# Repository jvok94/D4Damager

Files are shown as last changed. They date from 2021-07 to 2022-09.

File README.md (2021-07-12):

# D4 Damager
The D4 Damager is a fully-featured broadcast audio processor for AM or FM broadcasting. It can also be used as a ham radio voice processor. The D4 Damager combines six main 
features:

* **Fast peak limiting:** Prevents loud sounds from overmodulating your transmitter.
* **Compression:** A high (variable) gain input stage allows you to optionally overdrive the limiter, turning it into a compressor. This increases your audio volume without 
overmodulating, allowing you to better overcome background noise and compete with other stations.
* **Peak clipping:** Catches brief transients that overshoot the limiter, to prevent even very brief overmodulation. The limiter ensures that any clipping will only be brief and 
so does not much affect the sound.
* **Pre-emphasis:** Required for all FM transmitters, a modified version of pre-emphasis can also be used with AM transmitters to improve clarity.
* **Variable de-emphasis:** Automatically rolls off some or all of the pre-emphasis as necessary to prevent overmodulation due to the high-frequency boost.
* **Low-pass filter**: Rolls off any high frequency content that exceeds the transmitter's allowed bandwidth.

Full technical documentation will be added as soon as I get round to it.

## D4 Damager Main Board

This board implements a complete mono audio processor. For mono operation, two input connectors (J5 and J6) are provided to sum stereo sources to mono. Two boards can be linked 
together for stereo operation by joining the "STEREO LINK" connector (J4) on each board.

The PCB includes a full power supply requiring only a 15-0-15VAC (30VAC center tapped) supply from an external transformer. The power supply on a single PCB is capable of 
powering a full stereo system including all accessories (simply leave the power supply components un-populated on the second PCB). +/-15VDC power is also available on the two 
"EXT PWR" connectors (J8 and J9). Alternatively these connectors can be used to power the D4 Damager from an external +/-15VDC regulated PSU, in which case there is no need to 
fit the power supply components on the main PCB.

Controls are provided for:

* **Input gain (RV6):** Used both to match the D4 Damager to the signal level from the external audio source, and also to control how hard the limiter is driven to achieve the 
desired amount of compression.
* **Release time (RV3):** Controls how quickly the compressor/limiter returns to full gain after a transient. Influences how aggressive the compressor will sound.
* **Ratio (RV1):** Sets the maximum gain of the compressor/limiter during quiet passages. Useful to prevent excessive gain from boosting background noise, hum, hiss, etc.
* **Clipper clearance (RV4):** Sets the difference (clearance) between the limiter's output level and the clipper's clipping level. Used to trade off between maximum volume and 
minimum distortion.
* **Output gain (RV5):** Used to match the output level to your transmitter. Has no affect on the sound.

In a mono system, you have the choice of using either PCB-mount potentiometers (Bourns PTD90 series), or external panel-mount potentiometers wired to the board. In a stereo 
system, you will need to use panel-mount dual gang potentiometers to control both channels at once. In this case the two series connected dual-gang 500k potentiometers (RV1 and 
RV3) can be replaced with single 1M units. Take care to use the correct potentiometer law (RV4-RV6 are antilog types, which are unusual).

## LED Meter Bridge

Optional accessory containing four separate six-segment LED meters showing:

* Input signal level/limiter drive (VU response ref. to +12VU)
* Limiter gain reduction (reads right-to-left as standard for compressors)
* Pre-emphasis reduction (reads right-to-left)
* Output signal level (VU response ref. to +6VU)

Single connection to the main PCB via "METER BRIDGE" connector (J3) carries all signals and power. Use two PCBs in a stereo system.

## Balanced IO Card

Converts unbalanced inputs and outputs from/to balanced signals for connection to professional studio equipment. Contains two balanced receivers for stereo input, and two 
balanced transmitters for stereo output. Additionally contains two MONITOR outputs which are fully de-emphasised to drive studio monitors. All balanced inputs and outputs are 
available on both XLR and 1/4" TRS connectors.

Powered from main PCB via "EXT PWR" connector (J8 or J9).

## BoM Versions

Several different BoM versions are available to account for different broadcast standards around the world:

* **BoM fm na.xlsx:** For FM broadcasters in ITU Region 2 (North/South America). 15kHz audio bandwidth, 75us pre-emphasis time constant.
* **BoM fm row.xlsx:** For FM broadcasters in ITU Regions 1 (Africa, Europe, Middle East, North Asia) and 3 (South Asia, Oceania). 15kHz audio bandwidth, 50us pre-emphasis time 
constant.
* **BoM am na.xlsx:** For AM broadcasters in ITU Region 2 (North/South America). 5kHz audio bandwdith, pre-emphasis according to NRSC-1-C curve.
* **BoM am row.xlsx:** For AM broadcasters in ITU Regions 1 (Africa, Europe, Middle East, North Asia) and 3 (South Asia, Oceania). 4.5kHz audio bandwidth, pre-emphasis 
according to modified version of NRSC-1-C curve for reduced bandwidth.

BoM variants apply to main PCB and balanced IO card. LED VU meter card is the same worldwide.

## Initial calibration

You will need:

* Multimeter or DC voltmeter
* Dual-channel oscilloscope or audio millivolt meter
* Sine wave audio signal generator (you can use an app on your phone/PC for this, e.g. https://play.google.com/store/apps/details?id=com.keuwl.functiongenerator)

### Main PCB

Calibration should be done with no signal applied.

1. Adjust RV2 (SET DC) for 0.0mV DC offset on U1 pin 7.
2. Adjust RV7 (SET DC) for 0.0mV DC offset on U6 pin 1.

### LED VU Meter

Calibration should be done with LED VU meter PCB connected to main PCB. Make sure controls on main PCB are set as follows:

* RV1, RV3 fully clockwise.
* RV4, RV5, RV6 fully counter-clockwise.

1. Adjust RV1 (on the LED VU meter PCB) for -1.736VDC at junction of R6/R7.
2. Connect signal generator to main PCB input connector (J5). Do not apply a signal yet.
3. Connect oscilloscope channel 1 probe to main PCB input connector (J6), and channel 2 probe to main PCB output connector (J1). Use the connector shells for the ground clips.
4. Set signal generator output to 100mV p-p at 1kHz.
5. By comparing the signal levels on oscilloscope channels 1/2, measure the system gain.
6. Increase the signal generator output voltage while monitoring the gain on the oscilloscope, until the system gain has fallen 18dB below the previously measured level. This 
will require some back-and-forth between the signal generator and the oscilloscope.
7. Adjust RV3 (on the LED VU meter PCB) until D17 just lights up.
8. Without changing any signal levels, measure the DC voltage at U3 pin 6 on the main PCB.
9. Adjust the signal generator output level until the DC voltage at U3 pin 2 on the main PCB matches the voltage measured in step 8.
10. Adjust RV2 (on the LED VU meter PCB) until D23 just lights up.

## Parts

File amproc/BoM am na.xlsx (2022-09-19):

Reference | Quantity | Value | Footprint | Description | Manufacturer | Part number | Supplier | Order code | Price | Total | Notes
C1 C25 | 2 | 100p | Radial disc W4mm T2.6mm S2.5mm | 100pF 50V 5% C0G | Vishay | K101J15C0GF5TL2 | Farnell | 2860078 | £0.0713 | £0.1426
C10 C27 | 2 | 470p | Radial disc W4mm T2.5mm S5mm | 470pF 60V 5% C0G | Murata | RDE5C1H471J0M1H03A | Farnell | 2990775 | £0.1600 | £0.3200
C14 C13 | 2 | 1000u 35V | Radial can D12mm S5mm | 1000uF 35V 20% 105C electrolytic | Kemet | ESY108M035AL4AA | Farnell | 2835188 | £0.4390 | £0.8780
C17 C18 C19 C21 C20 C22 C23 | 7 | 100n | Radial disc W4mm T2.6mm S5mm | 100nF 50V 10% X7R | Vishay | K104K15X7RF53H5 | Farnell | 1141777 | £0.0823 | £0.5761
C3 C7 | 2 | 100n | Radial box W7.2mm T2.5mm S5mm | 100nF 63V 10% film | Kemet | R82DC3100AA50K | Farnell | 2763208 | £0.1280 | £0.2560
C24 | 1 | 150n | Radial box W7.2mm T2.5mm S5mm | 150nF 63V 10% film | Kemet | R82DC3150DQ60K | Farnell | 2446334 | £0.1370 | £0.1370
C26 C29 C16 C15 C9 C30 | 6 | 47u 25V | Radial can D5mm S2mm | 47uF 25V 20% 105C electrolytic | Kemet | ESH476M025AC3AA | Farnell | 2068762 | £0.0745 | £0.4470
C4 C11 C28 | 3 | 1n | Radial box W7.2mm T2.5mm S5mm | 1nF 100V 5% film | Kemet | R82EC1100Z350J | Farnell | 1679411 | £0.1300 | £0.3900
C5 | 1 | 4n7 | Radial box W7.2mm T2.5mm S5mm | 4.7nF 100V 10% film | Kemet | R82EC1470DQ50K | Farnell | 2763226 | £0.1100 | £0.1100
C8 C12 C6 C2 | 4 | 1u | Radial box W7.2mm T5mm 5mm | 1uF 63V 10% film | Kemet | R82DC4100AA60K | Farnell | 2763215 | £0.2750 | £1.1000
D13 | 1 | RED | T1-3/4 | 5mm 10mA red LED | Multicomp | MCL053PD | Farnell | 1581136 | £0.0609 | £0.0609
D4 D5 D6 D1 D2 D3 | 6 | 1N4148 | DO-35/DO-204AH | 100V 150mA silicon signal diode | Multicomp | 1N4148 (DO-35) | Farnell | 2675146 | £0.0319 | £0.1914
D7 D8 D9 D10 D12 D11 | 6 | 1N4001 | DO-204AL | 50V 1A silicon power diode | ON Semiconductor | 1N4001RLG | Farnell | 2822512 | £0.1930 | £1.1580
J1 J5 J6 | 3 |  | NYS354 | NYS354 | Rean | NYS354 | Mouser | 568-NYS354 | £0.5900 | £1.7700
J2 | 1 | AC IN | 39-28-1043 | 2x2-pin 4.20mm pitch shrouded header | Molex | 39-28-1043 | Farnell | 9732098 | £0.5810 | £0.5810 | Mates with Molex 39-01-2040 housing
J3 | 1 | METER BRIDGE | B7B-XH-A | 1x7-pin 2.5mm pitch shrouded header | JST | B7B-XH-A (LF)(SN) | Farnell | 1516283 | £0.2470 | £0.2470 | Mates with JST XHP-7
J4 | 1 | STEREO LINK | B5B-XH-A | 1x5-pin 2.5mm pitch shrouded header | JST | B5B-XH-A (LF)(SN) | Farnell | 1516281 | £0.1320 | £0.1320 | Mates with JST XHP-5
J7 | 1 | CHASSIS | TAB37800568 | 2.8x0.51mm PCB terminal | JST | TAB 37800568(MSTIN) | Farnell | 3625552 | £0.0252 | £0.0252 | Mates with any 2.8x0.51mm crimp terminal
J8 J9 | 2 | EXT POWER | B3B-XH-A | 1x3-pin 2.5mm pitch shrouded header | JST | B3B-XH-A (LF)(SN) | Farnell | 1516277 | £0.0925 | £0.1850
Q5 Q3 Q2 | 3 | BC546 | TO-92 | 100mA 65V NPN BJT | ON Semiconductor | BC546BTF | Farnell | 2453787 | £0.1510 | £0.4530
Q8 Q7 Q9 Q6 Q4 Q1 | 6 | BC556 | TO-92 | 100mA 65V PNP BJT | ON Semiconductor | BC556BTF | Farnell | 2453802 | £0.1640 | £0.9840
R10 | 1 | 430k | Axial 6.8mm | 530k 0.6W 1% metal film | Multicomp | MCMF006FF4303A50 | Farnell | 2401823 | £0.0207 | £0.0207
R13 R4 | 2 | 56 | Axial 6.8mm | 56R 0.6W 1% metal film | Multicomp | MCMF006FF560JA50 | Farnell | 2401720 | £0.0288 | £0.0576
R14 | 1 | 75k | Axial 6.8mm | 75k 0.6W 1% metal film | Multicomp | MCMF006FF7502A50 | Farnell | 2401804 | £0.0288 | £0.0288
R19 R3 | 2 | 8k2 | Axial 6.8mm | 8.2k 0.6W 1% metal film | Multicomp | MCMF006FF8201A50 | Farnell | 2401778 | £0.0284 | £0.0568
R2 | 1 | 82k | Axial 6.8mm | 82k 0.6W 1% metal film | Multicomp | MCMF006FF8202A50 | Farnell | 2401805 | £0.0300 | £0.0300
R20 | 1 | 3k9 | Axial 6.8mm | 3.9k 0.6W 1% metal film | Multicomp | MCMF006FF3901A50 | Farnell | 2401768 | £0.0302 | £0.0302
R21 | 1 | 12k | Axial 6.8mm | 12k 0.6W 1% metal film | Multicomp | MCMF006FF1202A50 | Farnell | 2401783 | £0.0284 | £0.0284
R24 | 1 | 270k | Axial 6.8mm | 270k 0.6W 1% metal film | Multicomp | MCMF006FF2703A50 | Farnell | 2401818 | £0.0286 | £0.0286
R26 | 1 | 22k | Axial 6.8mm | 22k 0.6W 1% metal film | Multicomp | MCMF006FF2202A50 | Farnell | 2401789 | £0.0300 | £0.0300
R30 | 1 | 3k3 | Axial 6.8mm | 3.3k 0.6W 1% metal film | Multicomp | MCMF006FF3301A50 | Farnell | 2401766 | £0.0288 | £0.0288
R31 R45 | 2 | 24k | Axial 6.8mm | 24k 0.6W 1% metal film | Multicomp | MCMF006FF2402A50 | Farnell | 2401790 | £0.0379 | £0.0758
R32 R46 | 2 | 15k | Axial 6.8mm | 15k 0.6W 1% metal film | Multicomp | MCMF006FF1502A50 | Farnell | 2401785 | £0.0379 | £0.0758
R34 R15 R18 R7 R5 | 5 | 100 | Axial 6.8mm | 100R 0.6W 1% metal film | Multicomp | MCMF006FF1000A50 | Farnell | 2401727 | £0.0300 | £0.1500
R36 | 1 | 68k | Axial 6.8mm | 68k 0.6W 1% metal film | Multicomp | MCMF006FF6802A50 | Farnell | 2401803 | £0.0288 | £0.0288
R37 R38 | 2 | 470 | Axial 6.8mm | 470R 0.6W 1% metal film | TE Connectivity | LR1F470R | Farnell | 2330156 | £0.0786 | £0.1572
R39 R40 R41 R27 | 4 | 27k | Axial 6.8mm | 27k 0.6W 1% metal film | Multicomp | MCMF006FF2702A50 | Farnell | 2401791 | £0.0284 | £0.1136
R42 R35 R16 R12 R6 | 5 | 2k2 | Axial 6.8mm | 2.2k 0.6W 1% metal film | Multicomp | MCMF006FF2201A50 | Farnell | 2401762 | £0.0283 | £0.1415
R43 R29 R1 | 3 | 100k | Axial 6.8mm | 100k 0.6W 1% metal film | Multicomp | MCMF006FF1003A50 | Farnell | 2401807 | £0.0284 | £0.0852
R44 | 1 | 560 | Axial 6.8mm | 560R 0.6W 1% metal film | Multicomp | MCMF006FF5600A50 | Farnell | 2401747 | £0.0288 | £0.0288
R47 R28 R33 R23 R17 R25 R22 R9 R11 R8 | 11 | 10k | Axial 6.8mm | 10k 0.6W 1% metal film | Multicomp | MCMF006FF1002A50 | Farnell | 2401780 | £0.0288 | £0.3168
R48 | 1 | 10 | Axial 6.8mm | 10R 0.6W 1% metal film | Multicomp | MCMF006FF100JA50 | Farnell | 2401700 | £0.0288 | £0.0288
RV1 RV3 | 2 | 500k LIN | PTD902 | 500k dual gang linear potentiometer | Bourns | PTD902-1015K-B504 | Mouser | 652-PTD9021015KB504 | £1.5000 | £3.0000
RV2 RV7 | 2 | 100 | T93YA | 100R multiturn trimmer | Vishay | T93YA101KT20 | Farnell | 1141397 | £1.4000 | £2.8000
RV6 RV5 RV4 | 3 | 10k ANTILOG | PTD901 | 10k single gang antilog potentiometer | Bourns | PTD901-2015F-C103 | Mouser | 652-PTD9012015FC103 | £1.2500 | £3.7500
U1 U2 U3 U5 U6 U7 | 6 | TL072 | DIP-8 | Dual 36V JFET input opamp | Texas Instruments | TL072ACP | Farnell | 3117783 | £0.9050 | £5.4300
U4 | 1 | LM13700 | DIP-16 | Dual OTA | Texas Instruments | LM13700N/NOPB | Farnell | 3118206 | £1.8400 | £1.8400
U8 | 1 | L7815 | TO-220 | Positive 15V linear regulator | ON Semiconductor | MC7815ACTG | Farnell | 2382331 | £0.4600 | £0.4600
U9 | 1 | L7915 | TO-220 | Negative 15V linear regulator | ON Semiconductor | MC7915ACTG | Mouser | 863-MC7915ACTG | £0.4040 | £0.4040
 |  |  |  |  |  |  |  |  | Total | £29.37

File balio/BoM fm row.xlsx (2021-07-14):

Reference | Quantity | Value | Footprint | Description | Manufacturer | Part number | Supplier | Order code | Price | Total | Notes
C1 C8 C9 C2 C11 C12 | 6 | 560p | Radial disc W4mm T2.6mm S2.5mm | 560pF 50V 5% C0G | Vishay | K561J15C0GF5TL2 | Farnell | 2860139 | £0.1350 | £0.8100
C3 C4 C5 C6 | 4 | 100n | Radial disc W4mm T2.6mm S5mm | 100nF 50V 10% X7R | Vishay | K104K15X7RF53H5 | Farnell | 1141777 | £0.0823 | £0.3292
C7 C10 | 2 | 1n5 | Radial box W7.2mm T2.5mm S5mm | 1.5nF 100V 5% film | Kemet | R82EC1150Z350J | Farnell | 1679412 | £0.1350 | £0.2700
C13 C14 | 2 | 100u 25V | Radial can D6mm S2.5mm | 100uF 25V 20% 85C electrolytic | Kemet | ESK107M025AE3AA | Farnell | 2068981 | £0.0805 | £0.1610
J1 J2 | 2 |  | NC3FAAH2 | 3-pin XLR female PCB mount | Neutrik | NC3FAAH2 | Farnell | 1310023 | £0.9390 | £1.8780
J3 J4 J11 J12 J15 J16 | 6 |  | CL12345 | 6.35mm TRS PCB mount | Cliff | CL12345 | Farnell | 2766186 | £1.1800 | £7.0800
J5 J6 J7 J8 | 4 |  | NYS354 | NYS354 | Rean | NYS354 | Mouser | 568-NYS354 | £0.5900 | £2.3600
J9 J10 J13 J14 | 4 |  | NC3MAAH | 3-pin XLR male PCB mount | Neutrik | NC3MAAH | Farnell | 1310044 | £0.8790 | £3.5160
J17 J18 | 2 | POWER | B3B-XH-A | 1x3-pin 2.5mm pitch shrouded header | JST | B3B-XH-A (LF)(SN) | Farnell | 1516277 | £0.0925 | £0.1850
R1 R2 R3 R4 R24 R26 R23 R25 R27 R29 R28 R30 | 12 | 2k2 | Axial 6.8mm | 2.2k 0.6W 1% metal film | Multicomp | MCMF006FF2201A50 | Farnell | 2401762 | £0.0283 | £0.3396
R5 R9 R13 R10 R11 R14 R12 R6 R17 R21 R18 R19 R22 R20 | 14 | 220 | Axial 6.8mm | 220R 0.6W 1% metal film | Multicomp | MCMF006FF2200A50 | Farnell | 2401736 | £0.0288 | £0.4032
R7 R15 | 2 | 30k | Axial 6.8mm | 30k 0.6W 1% metal film | Multicomp | MCMF006FF3002A50 | Farnell | 2401792 | £0.0307 | £0.0614
R8 R16 | 2 | 3k6 | Axial 6.8mm | 3.6k 0.6W 1% metal film | Multicomp | MCMF006FF3601A50 | Farnell | 2401767 | £0.0282 | £0.0564
U1 U2 | 2 | INA134 | DIP-8 | 36V balanced audio receiver | Texas Instruments | INA134PA | Farnell | 3005742 | £2.9000 | £5.8000
U3 U4 | 2 | TL072 | DIP-8 | Dual 36V JFET input opamp | Texas Instruments | TL072ACP | Farnell | 3117783 | £0.9050 | £1.8100
 |  |  |  |  |  |  |  |  | Total | £25.06

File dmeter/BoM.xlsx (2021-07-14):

Reference | Quantity | Value | Footprint | Description | Manufacturer | Part number | Supplier | Order code | Price | Total | Notes
C1 C2 | 2 | 100u 25V | Radial can D6mm S2.5mm | 100uF 25V 20% 85C electrolytic | Kemet | ESK107M025AE3AA | Farnell | 2068981 | £0.0805 | £0.1610
C11 C12 | 2 | 560n | Radial box W7.2mm T4.5mm S5mm | 560nF 63V 10% film | Kemet | MMK5564K63J03L4BULK | Mouser | 80-MMK5564K63J03L4 | £0.4650 | £0.9300
C3 C4 C5 C6 C9 C10 C13 C14 C15 C16 | 10 | 100n | Radial disc W4mm T2.6mm S5mm | 100nF 50V 10% X7R | Vishay | K104K15X7RF53H5 | Farnell | 1141777 | £0.0823 | £0.8230
C7 C8 | 2 | 33p | Radial disc W4mm T2.5mm S2.5mm | 33pF 50V 5% C0G | Vishay | K330J15C0GF5TL2 | Farnell | 2860122 | £0.0970 | £0.1940
D1 D5 D3 D2 D6 D4 D7 D8 | 8 | 1N4148 | DO-35/DO-204AH | 100V 150mA silicon signal diode | Multicomp | 1N4148 (DO-35) | Farnell | 2675146 | £0.0319 | £0.2552
D13 D31 | 2 | YELLOW | T1-3/4 | 5mm 20mA yellow LED | Multicomp | MCL053YD | Farnell | 1581139 | £0.0958 | £0.1916
D14 D32 | 2 | RED | T1-3/4 | 5mm 10mA red LED | Multicomp | MCL053PD | Farnell | 1581136 | £0.0609 | £0.1218
D9 D10 D11 D12 D15 D16 D17 D18 D19 D20 D21 D22 D23 D24 D25 D26 D27 D28 D29 D30 | 20 | GREEN | T1-3/4 | 5mm 20mA green LED | Multicomp | MCL053GD | Farnell | 1581138 | £0.0746 | £1.4920
J1 | 1 | INPUT | B7B-XH-A | 1x7-pin 2.5mm pitch shrouded header | JST | B7B-XH-A (LF)(SN) | Farnell | 1516283 | £0.2470 | £0.2470 | Mates with JST XHP-7
Q2 Q3 Q4 Q5 Q1 | 5 | BC556 | TO-92 | 100mA 65V PNP BJT | ON Semiconductor | BC556BTF | Farnell | 2453802 | £0.1640 | £0.8200
R1 R2 | 2 | 1k | Axial 6.8mm | 1k 0.6W 1% metal film | Multicomp | MCMF006FF1001A50 | Farnell | 2401753 | £0.0303 | £0.0606
R11 R21 | 2 | 390 | Axial 6.8mm | 390R 0.6W 1% metal film | Multicomp | MCMF006FF3900A50 | Farnell | 2401742 | £0.0288 | £0.0576
R13 R10 R15 R8 R17 R14 R12 R16 R9 R19 R24 R25 R27 | 13 | 10k | Axial 6.8mm | 10k 0.6W 1% metal film | Multicomp | MCMF006FF1002A50 | Farnell | 2401780 | £0.0288 | £0.3744
R20 R18 | 2 | 1M | Axial 6.8mm | 1M 0.6W 1% metal film | Multicomp | MCMF006FF1004A50 | Farnell | 2401833 | £0.0300 | £0.0600
R26 | 1 | 30k | Axial 6.8mm | 30k 0.6W 1% metal film | Multicomp | MCMF006FF3002A50 | Farnell | 2401792 | £0.0307 | £0.0307
R28 R22 R23 | 3 | 5k6 | Axial 6.8mm | 5.6k 0.6W 1% metal film | Multicomp | MCMF006FF5601A50 | Farnell | 2401774 | £0.0281 | £0.0843
R29 R30 R31 R32 | 4 | 100 | Axial 6.8mm | 100R 0.6W 1% metal film | Multicomp | MCMF006FF1000A50 | Farnell | 2401727 | £0.0300 | £0.1200
R3 | 1 | 2k | Axial 6.8mm | 2k 0.6W 1% metal film | Multicomp | MCMF006FF2001A50 | Farnell | 2401761 | £0.0300 | £0.0300
R4 | 1 | 3k9 | Axial 6.8mm | 3.9k 0.6W 1% metal film | Multicomp | MCMF006FF3901A50 | Farnell | 2401768 | £0.0302 | £0.0302
R5 | 1 | 8k2 | Axial 6.8mm | 8.2k 0.6W 1% metal film | Multicomp | MCMF006FF8201A50 | Farnell | 2401778 | £0.0284 | £0.0284
R6 | 1 | 16k | Axial 6.8mm | 16k 0.6W 1% metal film | Multicomp | MCMF006FF1602A50 | Farnell | 2401786 | £0.0286 | £0.0286
R7 | 1 | 240k | Axial 6.8mm | 240k 0.6W 1% metal film | Multicomp | MCMF006FF2403A50 | Farnell | 2401817 | £0.0266 | £0.0266
RV1 RV2 RV3 | 3 | 10k | T93YA | 10k multiturn trimmer | Vishay | T93YA103KT20 | Farnell | 1141404 | £1.4400 | £4.3200
U1 U2 U3 U4 | 4 | TL072 | DIP-8 | Dual 36V JFET input opamp | Texas Instruments | TL072ACP | Farnell | 3117783 | £0.9050 | £3.6200
U5 U6 U7 U8 U9 U10 | 6 | LM339 | DIP-14 | Quad 36V open-drain output comparator | Texas Instruments | LM339AN | Farnell | 3118450 | £0.4770 | £2.8620
 |  |  |  |  |  |  |  |  | Total | £16.97

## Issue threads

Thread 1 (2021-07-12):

J2 on main PCB - pin dimensions wrong

jvok94, 2021-07-12:
"AC IN" connector (J2) on main PCB, hole dimensions are too small to fit the pins. Had to wire transformer directly to PCB as workaround.

Increase these hole dimensions to match recommended footprint in datasheet: https://www.molex.com/pdm_docs/sd/039281043_sd.pdf

jvok94, 2021-07-17:
Fixed in commit 2672a2ff3da69e6f78261edbda0c9bd560d376c6

Closed 2021-07-17.

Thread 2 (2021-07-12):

Excessive high-frequency roll-off due to C25

jvok94, 2021-07-12:
Capacitor C25 on main PCB forms part of a passive LPF at the input to prevent RF interference from getting into the card. However the current value (560pF) causes a bit too much attenuation at high-frequencies when combined with the main audio LPFs. Changing this to 100pF will still give enough RF attenuation without attenuating audio frequencies.

jvok94, 2021-07-14:
Implemented in commit c5f9b9964f1abe7292039a8ce1eda6c55f51f18e

Closed 2021-07-12.

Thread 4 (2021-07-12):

Correct reference levels of input and output meters

jvok94, 2021-07-12:
On LED VU Meter board, labelling on schematic suggests full scale for input meter is +12VU, and for output meter is +6VU. However looking at values of attenuators (R26/R27 for input meter, R24/R25 for output meter), this is actually the other way round, i.e. +6VU full scale on input meter, +12VU full scale on output meter.

Need to change attenuator resistors so that meter response matches labelling.

jvok94, 2021-07-14:
Implemented in commit 27dbdb92ca757b2c75ce1d5698e8d7ae3e768ec6

Closed 2021-07-12.

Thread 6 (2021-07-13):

Review pre-emphasis circuit component values

jvok94, 2021-07-13:
While working on #5 it was discovered that the wrong formula had been used in the spreadsheet to calculate the zero frequency. The formula uses the calculated ideal resistor value for R20 instead of the actual (closest E24) value. These results are used to compare multiple different component selections and choose the one with the lowest error. As a result, the values chosen might not actually be the best possible choices.

Review all design variants to make sure the components used actually give the closest match to the proper pre-emphasis curve, and update schematic and BoM if necessary. Don't need to do this for AM RoW variant as this has already been done as part of #5.

jvok94, 2021-07-17:
Fixed in commit 3e532c62e887ab937022e106463bf8e8b192fe5a

Closed 2021-07-17.

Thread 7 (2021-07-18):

Limiter/de-emphasis metering feeds after envelope filter

jvok94, 2021-07-18:
Currently the limiter gain reduction meter and de-emphasis meter are both driven directly from the rectifier outputs (pulsed DC) rather than from the envelope filter (slowly changing DC). This makes the meters very flickery and fast responding, particularly noticeable against the much slower responding input/output VU meters.

It also means that the meters do not accurately show how the limiter and de-emphasis are responding. During the attack period especially the meter will tend to read higher than it should due to the voltage drop across the attack timing resistor.

Circuit should be changed to take metering feeds directly from the envelope filter capacitor (C3/C7). Note that the stereo link connector should still go to the rectifier output.

N.b. might want to prototype this first.

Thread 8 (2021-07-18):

Changes to allow lower value pots for release and ratio controls

jvok94, 2021-07-18:
Both the release time (RV3) and ratio (RV1) controls need 1M pots. As these are not widely available, dual-gang 500k pots have been used instead, with the two gangs connected in series. This is fine for a mono setup, but for a stereo setup we'd need either a dual-gang 1M pot or a quad-gang 500k pot, neither of which is easy to find.

Try to come up with a circuit change that will allow the use of lower value pots without changing functionality. See also issue #9.

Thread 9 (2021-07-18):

Eliminate anti-log pots

jvok94, 2021-07-18:
Anti-log pots have been used for the input gain (RV2), output gain (RV5) and clipper headroom (RV4) controls. This is needed to get the correct logarithmic response as the pots are used in the feedback loops of opamps. However anti-log pots are more expensive and harder to find, especially in dual-gang versions (for a stereo unit).

See if circuit design can be changed to take pots outside of feedback loops, allowing normal log pots to be used.

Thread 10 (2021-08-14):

Voltage regulator pin-outs backwards

jvok94, 2021-08-14:
U8/U9 are intended to mount on bottom of PCB, but with tabs facing downwards for attaching to heatsink. On Rev. 1 design, standard horizontal TO-220 footprints were used but flipped to bottom layer. This incorrectly reverses pinout so regulator had to be mounted with tab facing upwards (in contact with PCB).

Can correct pinout by either putting footprints on top layer (despite mount on bottom layer), or better by using footprint designed for reverse mounting.

jvok94, 2022-09-19:
Fixed in commit 62207d1cf0d763c8c085fba6087937c6c2914390

Closed 2022-09-19.

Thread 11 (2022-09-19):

Migrate to Kicad 6

jvok94, 2022-09-19:

jvok94, 2022-09-19:
Fixed in commits b8368e85c7e27e8f117ae28eea41ff454eb6720c, 632c7e6a15b64aa0ff80a88db13cf60ca302454e and f54c9045ebc5bec713ae23f7bd7639c6c33cc0b2

Closed 2022-09-19.

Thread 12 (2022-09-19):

Rev 2 release

jvok94, 2022-09-19:
- Full check of schematic and PCB layout
- Check all BoMs match up with schematic
- Re-plot gerbers
- Full check of gerbers

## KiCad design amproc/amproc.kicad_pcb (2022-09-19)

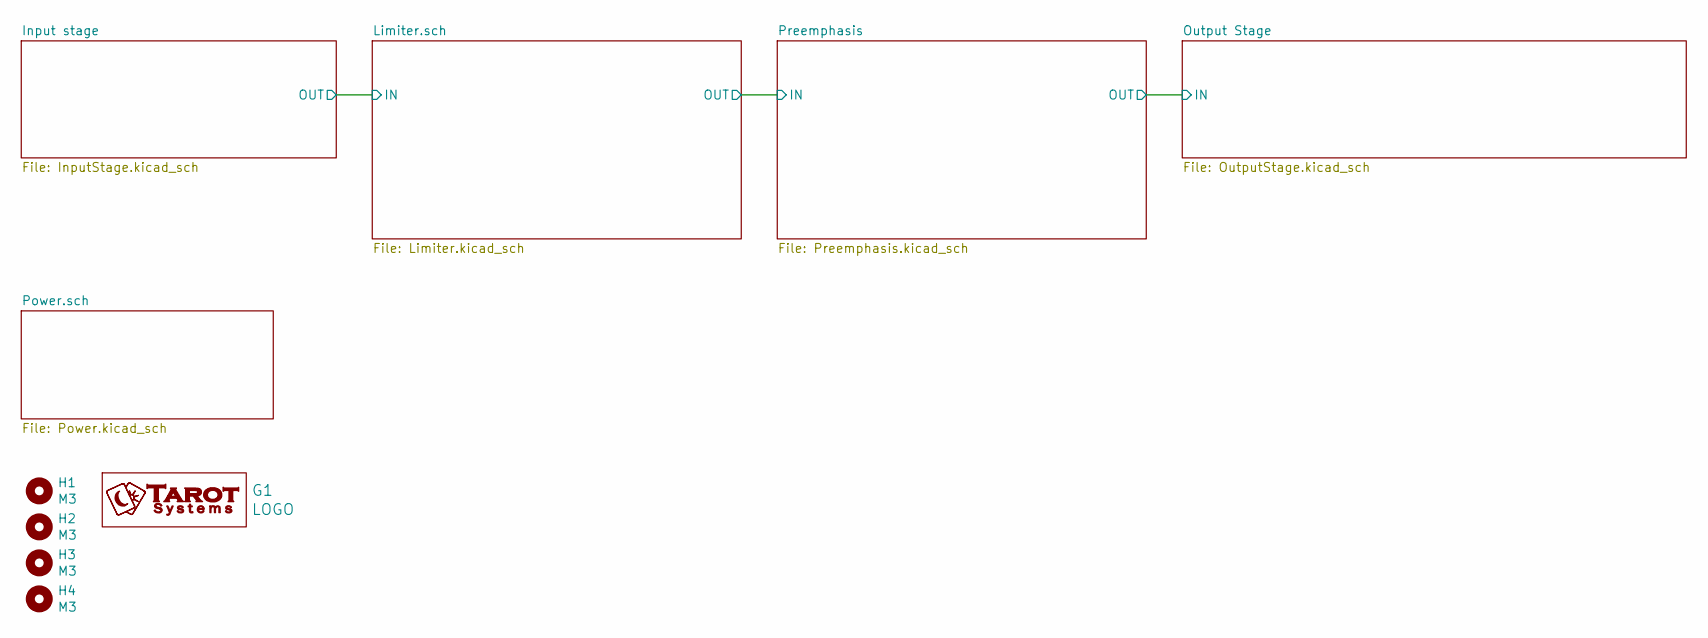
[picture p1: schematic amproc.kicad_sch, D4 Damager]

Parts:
G1: LOGO; tarot_logo_fsilk_25mm
H1, H2, H3, H4: M3; MountingHole_3.2mm_M3

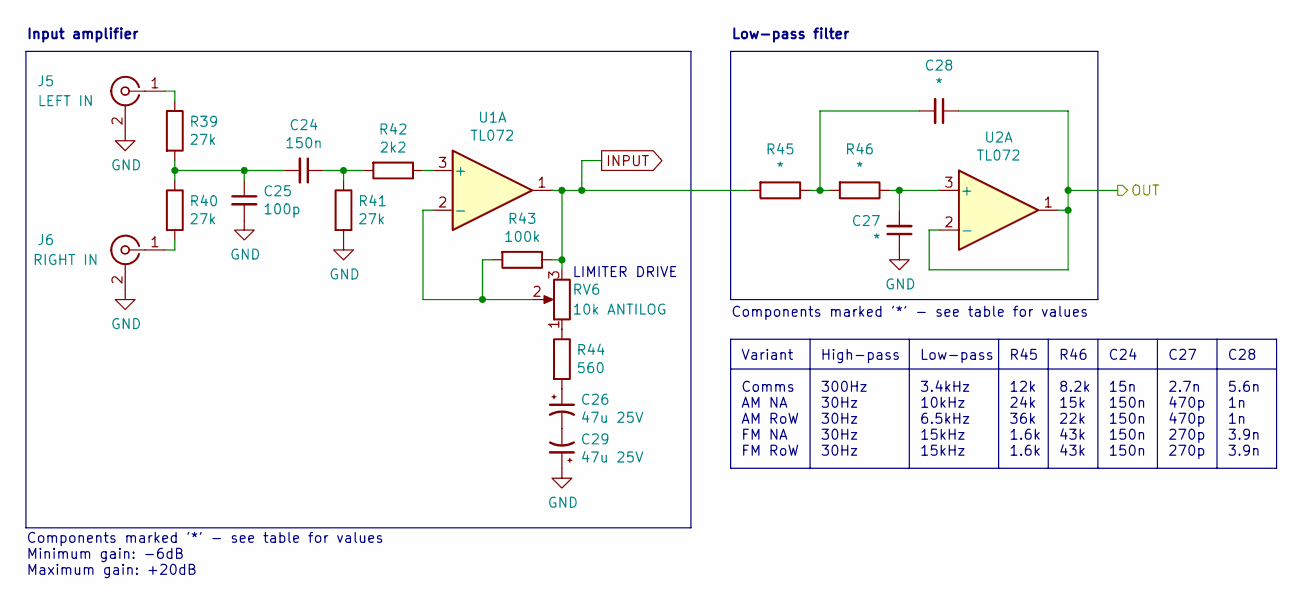
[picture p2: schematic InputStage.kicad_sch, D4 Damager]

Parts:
C24: 150n; C_Rect_L7.2mm_W2.5mm_P5.00mm_FKS2_FKP2_MKS2_MKP2
C25: 100p; C_Disc_D5.0mm_W2.5mm_P2.50mm
C26, C29: 47u 25V; CP_Radial_D5.0mm_P2.00mm
C27, C28: *; C_Rect_L7.2mm_W2.5mm_P5.00mm_FKS2_FKP2_MKS2_MKP2
J5: LEFT IN; NYS354
J6: RIGHT IN; NYS354
R39, R40, R41: 27k; R_Axial_DIN0207_L6.3mm_D2.5mm_P7.62mm_Horizontal_FabText
R42: 2k2; R_Axial_DIN0207_L6.3mm_D2.5mm_P7.62mm_Horizontal_FabText
R43: 100k; R_Axial_DIN0207_L6.3mm_D2.5mm_P7.62mm_Horizontal_FabText
R44: 560; R_Axial_DIN0207_L6.3mm_D2.5mm_P7.62mm_Horizontal_FabText
R45, R46: *; R_Axial_DIN0207_L6.3mm_D2.5mm_P7.62mm_Horizontal_FabText
RV6: 10k ANTILOG; PTD901-15K
U1, U2: TL072; DIP-8_W7.62mm_LongPads

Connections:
/Input stage/OUT: C28.1, U2.1, U2.2 (-); also elsewhere on the board
GND: C25.2, C27.1, C29.1, J5.2 (Ext), J6.2 (Ext), R41.2; also elsewhere on the board
INPUT: R43.1, R45.2, RV6.3, U1.1; also elsewhere on the board
unnamed: C24.1, R41.1, R42.2
unnamed: C24.2, C25.1, R39.2, R40.1
unnamed: C26.1, R44.2
unnamed: C26.2, C29.2
unnamed: C27.2, R46.1, U2.3 (+)
unnamed: C28.2, R45.1, R46.2
unnamed: J5.1 (In), R39.1
unnamed: J6.1 (In), R40.2
unnamed: R42.1, U1.3 (+)
unnamed: R43.2, RV6.2, U1.2 (-)
unnamed: R44.1, RV6.1

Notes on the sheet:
C24 15n 150n 150n 150n 150n
LIMITER DRIVE
C28 5.6n 1n 1n 3.9n 3.9n
R46 8.2k 15k 22k 43k 43k
Variant Comms AM NA AM RoW FM NA FM RoW
Low-pass filter
C27 2.7n 470p 470p 270p 270p
Components marked '*' - see table for values Minimum gain: -6dB Maximum gain: +20dB
Low-pass 3.4kHz 10kHz 6.5kHz 15kHz 15kHz
Components marked '*' - see table for values
High-pass 300Hz 30Hz 30Hz 30Hz 30Hz
Input amplifier
R45 12k 24k 36k 1.6k 1.6k

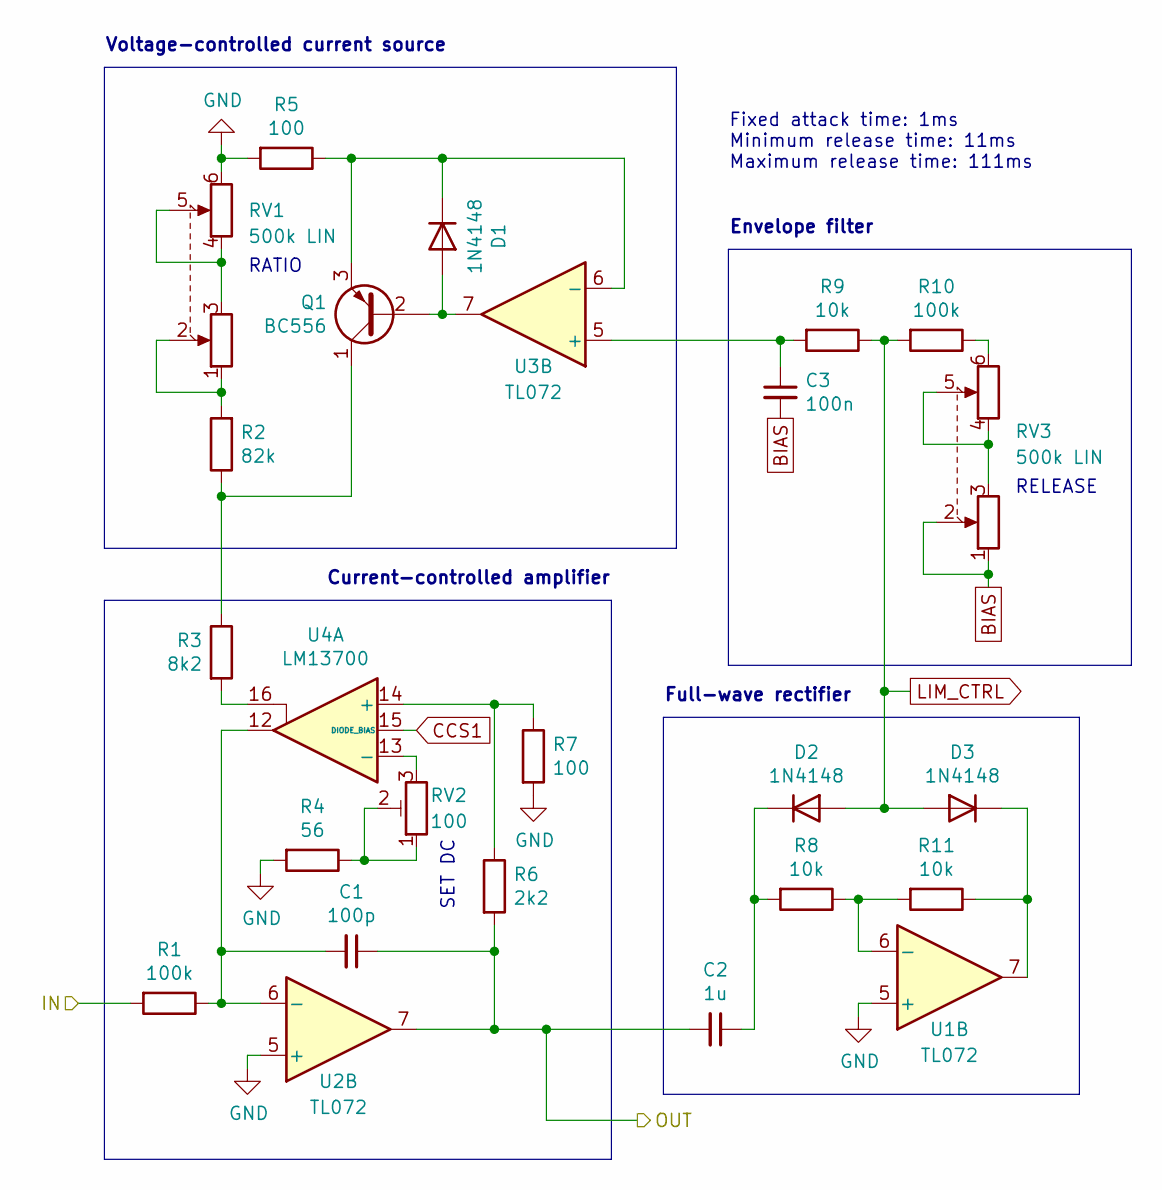
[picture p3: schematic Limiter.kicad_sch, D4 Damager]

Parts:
C1: 100p; C_Disc_D5.0mm_W2.5mm_P2.50mm
C2: 1u; C_Rect_L7.2mm_W5.5mm_P5.00mm_FKS2_FKP2_MKS2_MKP2
C3: 100n; C_Rect_L7.2mm_W2.5mm_P5.00mm_FKS2_FKP2_MKS2_MKP2
D1, D2, D3: 1N4148; D_DO-35_SOD27_P7.62mm_Horizontal
Q1: BC556; TO-92_Inline_Narrow_Oval
R1, R10: 100k; R_Axial_DIN0207_L6.3mm_D2.5mm_P7.62mm_Horizontal_FabText
R2: 82k; R_Axial_DIN0207_L6.3mm_D2.5mm_P7.62mm_Horizontal_FabText
R3: 8k2; R_Axial_DIN0207_L6.3mm_D2.5mm_P7.62mm_Horizontal_FabText
R4: 56; R_Axial_DIN0207_L6.3mm_D2.5mm_P7.62mm_Horizontal_FabText
R5, R7: 100; R_Axial_DIN0207_L6.3mm_D2.5mm_P7.62mm_Horizontal_FabText
R6: 2k2; R_Axial_DIN0207_L6.3mm_D2.5mm_P7.62mm_Horizontal_FabText
R8, R9, R11: 10k; R_Axial_DIN0207_L6.3mm_D2.5mm_P7.62mm_Horizontal_FabText
RV1, RV3: 500k LIN; PTD902-15K
RV2: 100; Potentiometer_Trimmer_Bourns_3296W_FabText
U1, U2, U3: TL072; DIP-8_W7.62mm_LongPads
U4: LM13700; DIP-16_W7.62mm_LongPads

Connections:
/Input stage/OUT: R1.2; also elsewhere on the board
/Limiter.sch/OUT: C1.1, C2.2, R6.2, U2.7; also elsewhere on the board
BIAS: C3.2, RV3.1, RV3.2; also elsewhere on the board
CCS1: U4.15 (DIODE_BIAS); also elsewhere on the board
GND: R4.2, R5.2, R7.2, RV1.6, U1.5 (+), U2.5 (+); also elsewhere on the board
LIM_CTRL: D2.2 (A), D3.2 (A), R9.1, R10.2; also elsewhere on the board
unnamed: C1.2, R1.1, U2.6 (-), U4.12
unnamed: C2.1, D2.1 (K), R8.2
unnamed: C3.1, R9.2, U3.5 (+)
unnamed: D1.1 (K), Q1.3 (E), R5.1, U3.6 (-)
unnamed: D1.2 (A), Q1.2 (B), U3.7
unnamed: D3.1 (K), R11.1, U1.7
unnamed: Q1.1 (C), R2.1, R3.1
unnamed: R2.2, RV1.1, RV1.2
unnamed: R3.2, U4.16
unnamed: R4.1, RV2.1, RV2.2
unnamed: R6.1, R7.1, U4.14 (+)
unnamed: R10.1, RV3.6
unnamed: R8.1, R11.2, U1.6 (-)
unnamed: RV1.3, RV1.4, RV1.5
unnamed: RV2.3, U4.13 (-)
unnamed: RV3.3, RV3.4, RV3.5

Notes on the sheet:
RATIO
SET DC
RELEASE
Fixed attack time: 1ms Minimum release time: 11ms Maximum release time: 111ms
Full-wave rectifier
Voltage-controlled current source
Envelope filter
Current-controlled amplifier

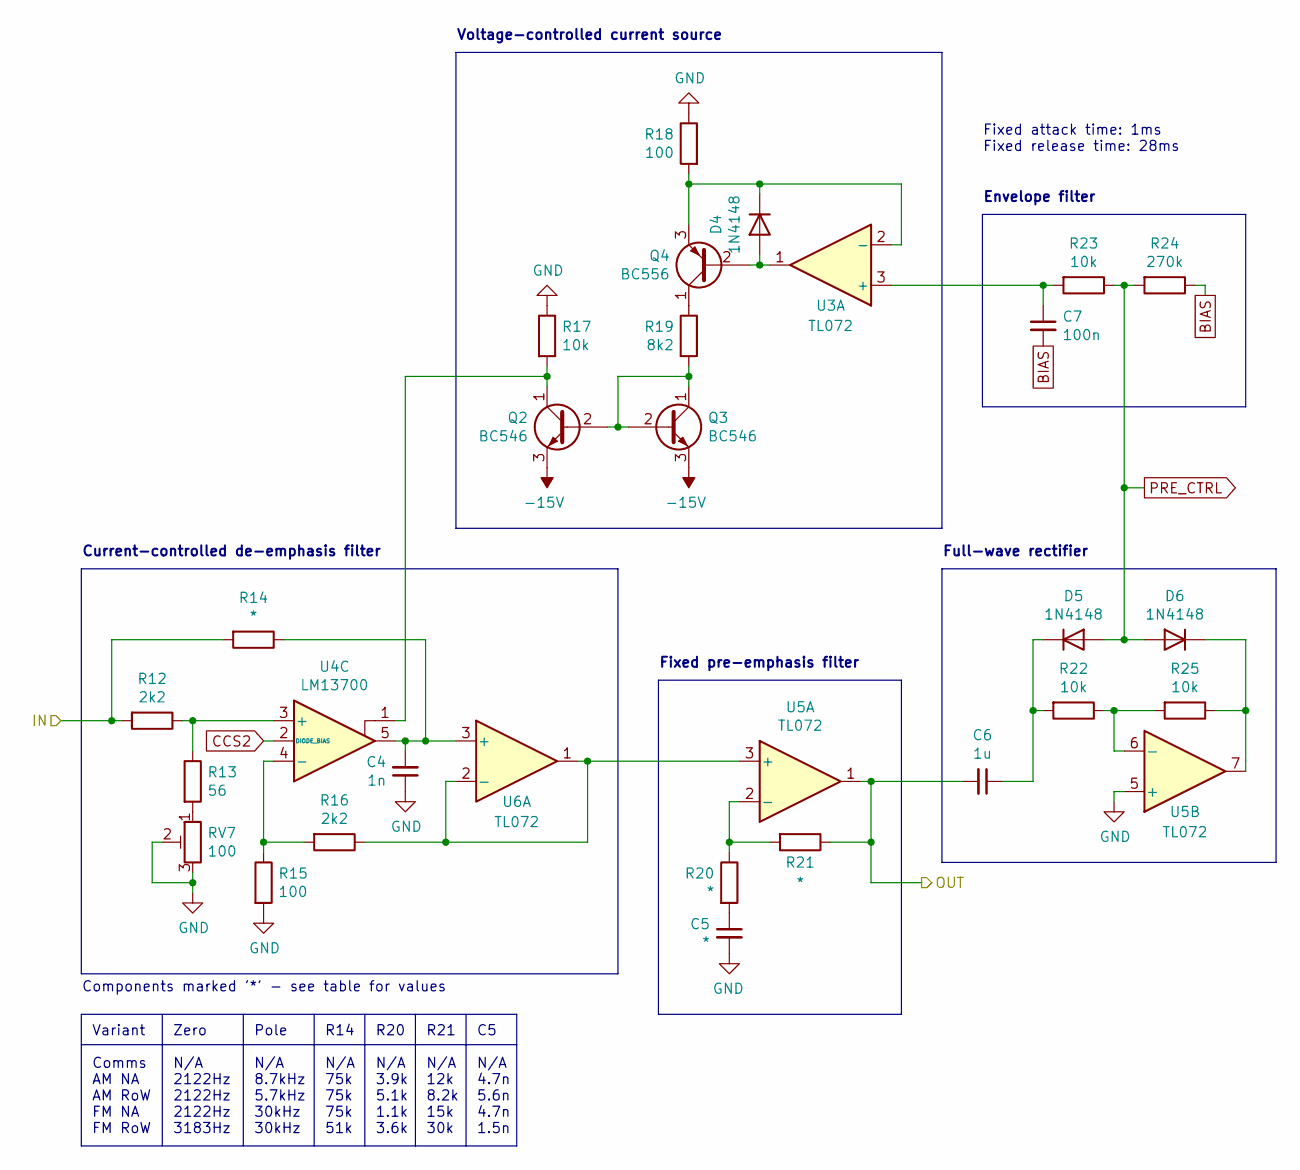
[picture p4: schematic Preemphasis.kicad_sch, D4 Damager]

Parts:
C4: 1n; C_Rect_L7.2mm_W2.5mm_P5.00mm_FKS2_FKP2_MKS2_MKP2
C5: *; C_Rect_L7.2mm_W2.5mm_P5.00mm_FKS2_FKP2_MKS2_MKP2
C6: 1u; C_Rect_L7.2mm_W5.5mm_P5.00mm_FKS2_FKP2_MKS2_MKP2
C7: 100n; C_Rect_L7.2mm_W2.5mm_P5.00mm_FKS2_FKP2_MKS2_MKP2
D4, D5, D6: 1N4148; D_DO-35_SOD27_P7.62mm_Horizontal
Q2, Q3: BC546; TO-92_Inline_Narrow_Oval
Q4: BC556; TO-92_Inline_Narrow_Oval
R12, R16: 2k2; R_Axial_DIN0207_L6.3mm_D2.5mm_P7.62mm_Horizontal_FabText
R13: 56; R_Axial_DIN0207_L6.3mm_D2.5mm_P7.62mm_Horizontal_FabText
R14, R20, R21: *; R_Axial_DIN0207_L6.3mm_D2.5mm_P7.62mm_Horizontal_FabText
R15, R18: 100; R_Axial_DIN0207_L6.3mm_D2.5mm_P7.62mm_Horizontal_FabText
R17, R22, R23, R25: 10k; R_Axial_DIN0207_L6.3mm_D2.5mm_P7.62mm_Horizontal_FabText
R19: 8k2; R_Axial_DIN0207_L6.3mm_D2.5mm_P7.62mm_Horizontal_FabText
R24: 270k; R_Axial_DIN0207_L6.3mm_D2.5mm_P7.62mm_Horizontal_FabText
RV7: 100; Potentiometer_Trimmer_Bourns_3296W_FabText
U3, U5, U6: TL072; DIP-8_W7.62mm_LongPads
U4: LM13700; DIP-16_W7.62mm_LongPads

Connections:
-15V: Q2.3 (E), Q3.3 (E); also elsewhere on the board
/Limiter.sch/OUT: R12.2, R14.2; also elsewhere on the board
/Output Stage/IN: C6.2, R21.1, U5.1; also elsewhere on the board
BIAS: C7.2, R24.1; also elsewhere on the board
CCS2: U4.2 (DIODE_BIAS); also elsewhere on the board
GND: C4.1, C5.2, R15.2, R17.1, R18.1, RV7.2, RV7.3, U5.5 (+); also elsewhere on the board
unnamed: C4.2, R14.1, U4.5, U6.3 (+)
unnamed: C5.1, R20.2
unnamed: C6.1, D5.1 (K), R22.2
unnamed: C7.1, R23.2, U3.3 (+)
unnamed: D4.1 (K), Q4.3 (E), R18.2, U3.2 (-)
unnamed: D4.2 (A), Q4.2 (B), U3.1
unnamed: D6.1 (K), R25.1, U5.7
unnamed: Q2.1 (C), R17.2, U4.1
unnamed: Q2.2 (B), Q3.1 (C), Q3.2 (B), R19.2
unnamed: Q4.1 (C), R19.1
unnamed: R12.1, R13.1, U4.3 (+)
unnamed: R13.2, RV7.1
unnamed: R15.1, R16.2, U4.4 (-)
unnamed: R16.1, U5.3 (+), U6.1, U6.2 (-)
unnamed: R20.1, R21.2, U5.2 (-)
unnamed: R22.1, R25.2, U5.6 (-)
PRE_CTRL: D5.2 (A), D6.2 (A), R23.1, R24.2; also elsewhere on the board

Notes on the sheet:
R21 N/A 12k 8.2k 15k 30k
Voltage-controlled current source
Fixed pre-emphasis filter
Fixed attack time: 1ms Fixed release time: 28ms
R14 N/A 75k 75k 75k 51k
Components marked '*' - see table for values
Variant Comms AM NA AM RoW FM NA FM RoW
Current-controlled de-emphasis filter
C5 N/A 4.7n 5.6n 4.7n 1.5n
Envelope filter
Full-wave rectifier
Pole N/A 8.7kHz 5.7kHz 30kHz 30kHz
Zero N/A 2122Hz 2122Hz 2122Hz 3183Hz
R20 N/A 3.9k 5.1k 1.1k 3.6k

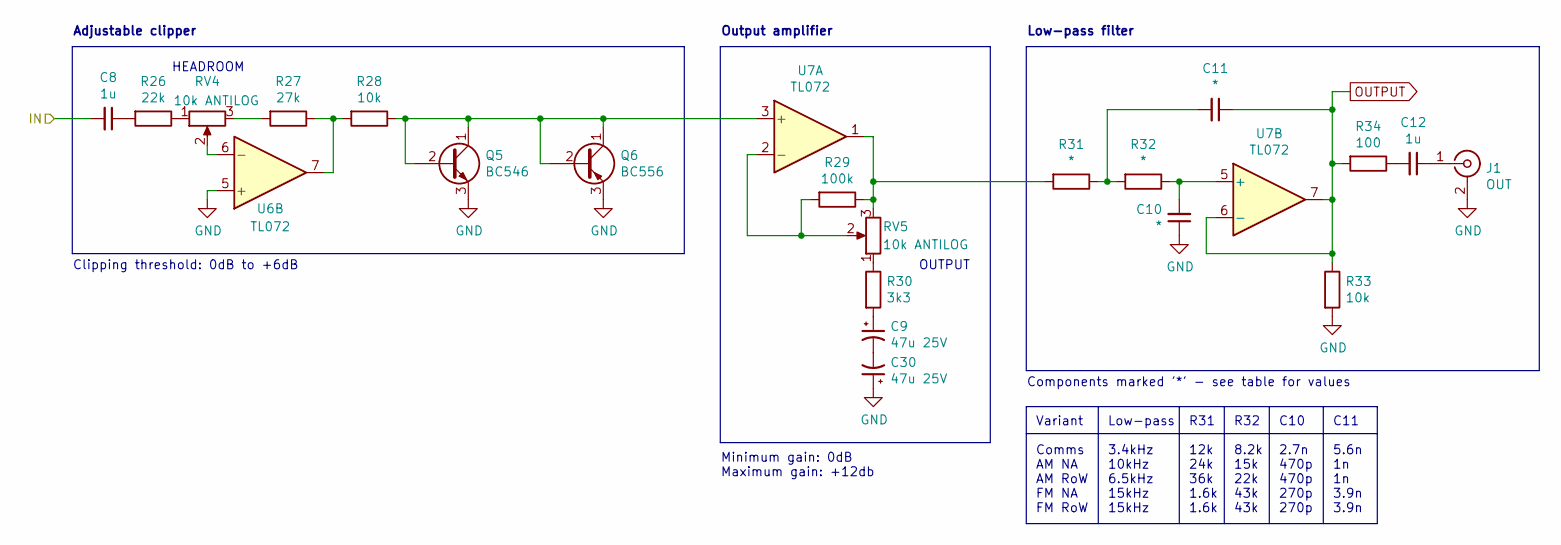
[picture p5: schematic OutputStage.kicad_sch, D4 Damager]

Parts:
C8, C12: 1u; C_Rect_L7.2mm_W5.5mm_P5.00mm_FKS2_FKP2_MKS2_MKP2
C9, C30: 47u 25V; CP_Radial_D5.0mm_P2.00mm
C10, C11: *; C_Rect_L7.2mm_W2.5mm_P5.00mm_FKS2_FKP2_MKS2_MKP2
J1: OUT; NYS354
Q5: BC546; TO-92_Inline_Narrow_Oval
Q6: BC556; TO-92_Inline_Narrow_Oval
R26: 22k; R_Axial_DIN0207_L6.3mm_D2.5mm_P7.62mm_Horizontal_FabText
R27: 27k; R_Axial_DIN0207_L6.3mm_D2.5mm_P7.62mm_Horizontal_FabText
R28, R33: 10k; R_Axial_DIN0207_L6.3mm_D2.5mm_P7.62mm_Horizontal_FabText
R29: 100k; R_Axial_DIN0207_L6.3mm_D2.5mm_P7.62mm_Horizontal_FabText
R30: 3k3; R_Axial_DIN0207_L6.3mm_D2.5mm_P7.62mm_Horizontal_FabText
R31, R32: *; R_Axial_DIN0207_L6.3mm_D2.5mm_P7.62mm_Horizontal_FabText
R34: 100; R_Axial_DIN0207_L6.3mm_D2.5mm_P7.62mm_Horizontal_FabText
RV4, RV5: 10k ANTILOG; PTD901-15K
U6, U7: TL072; DIP-8_W7.62mm_LongPads

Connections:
/Output Stage/IN: C8.2; also elsewhere on the board
GND: C10.1, C30.1, J1.2 (Ext), Q5.3 (E), Q6.3 (E), R33.2, U6.5 (+); also elsewhere on the board
unnamed: C8.1, R26.2
unnamed: C9.1, R30.2
unnamed: C10.2, R32.1, U7.5 (+)
unnamed: C11.2, R31.1, R32.2
unnamed: C12.1, J1.1 (In)
unnamed: C12.2, R34.1
unnamed: C9.2, C30.2
unnamed: Q5.1 (C), Q5.2 (B), Q6.1 (C), Q6.2 (B), R28.1, U7.3 (+)
unnamed: R26.1, RV4.1
unnamed: R27.1, R28.2, U6.7
unnamed: R27.2, RV4.3
unnamed: R29.1, R31.2, RV5.3, U7.1
unnamed: R29.2, RV5.2, U7.2 (-)
unnamed: R30.1, RV5.1
unnamed: RV4.2, U6.6 (-)
OUTPUT: C11.1, R33.1, R34.2, U7.6 (-), U7.7; also elsewhere on the board

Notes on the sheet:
HEADROOM
Adjustable clipper
Output amplifier
Minimum gain: 0dB Maximum gain: +12db
OUTPUT
R32 8.2k 15k 22k 43k 43k
Clipping threshold: 0dB to +6dB
R31 12k 24k 36k 1.6k 1.6k
Components marked '*' - see table for values
Low-pass 3.4kHz 10kHz 6.5kHz 15kHz 15kHz
C10 2.7n 470p 470p 270p 270p
Low-pass filter
Variant Comms AM NA AM RoW FM NA FM RoW
C11 5.6n 1n 1n 3.9n 3.9n

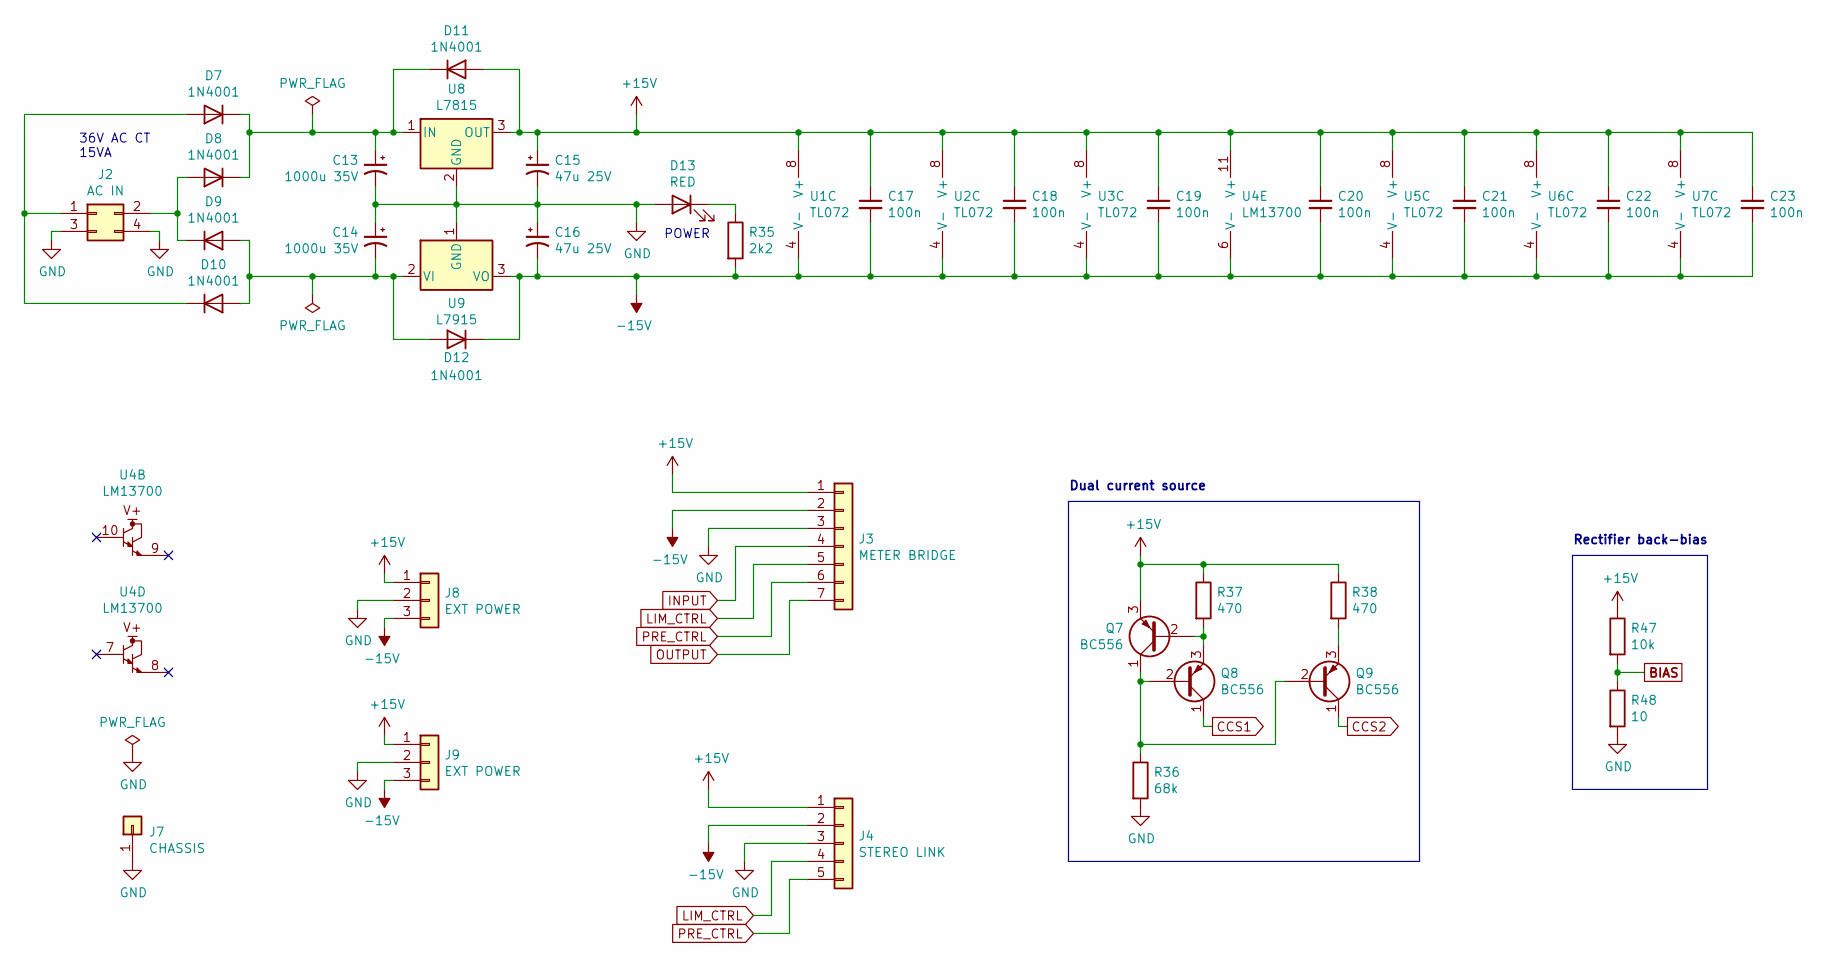
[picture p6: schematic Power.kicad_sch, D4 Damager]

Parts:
C13, C14: 1000u 35V; CP_Radial_D12.5mm_P5.00mm
C15, C16: 47u 25V; CP_Radial_D5.0mm_P2.00mm
C17, C18, C19, C20, C21, C22, C23: 100n; C_Disc_D4.7mm_W2.5mm_P5.00mm
D7, D8, D9, D10, D11, D12: 1N4001; D_DO-41_SOD81_P10.16mm_Horizontal
D13: RED; LED_D5.0mm
J2: AC IN; 39-28-1043
J3: METER BRIDGE; JST_XH_B07B-XH-A_07x2.50mm_Straight
J4: STEREO LINK; JST_XH_B05B-XH-A_05x2.50mm_Straight
J7: CHASSIS; TAB_378005.68
J8, J9: EXT POWER; JST_XH_B03B-XH-A_03x2.50mm_Straight
Q7, Q8, Q9: BC556; TO-92_Inline_Narrow_Oval
R35: 2k2; R_Axial_DIN0207_L6.3mm_D2.5mm_P7.62mm_Horizontal_FabText
R36: 68k; R_Axial_DIN0207_L6.3mm_D2.5mm_P7.62mm_Horizontal_FabText
R37, R38: 470; R_Axial_DIN0207_L6.3mm_D2.5mm_P7.62mm_Horizontal_FabText
R47: 10k; R_Axial_DIN0207_L6.3mm_D2.5mm_P7.62mm_Horizontal_FabText
R48: 10; R_Axial_DIN0207_L6.3mm_D2.5mm_P7.62mm_Horizontal_FabText
U1, U2, U3, U5, U6, U7: TL072; DIP-8_W7.62mm_LongPads
U4: LM13700; DIP-16_W7.62mm_LongPads
U8: L7815; TO-220-3_Horizontal_TabUp
U9: L7915; TO-220-3_Horizontal_TabUp

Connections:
+15V: C15.1, C17.1, C18.1, C19.1, C20.1, C21.1, C22.1, C23.1, D11.2 (A), J3.1, J4.1, J8.1, J9.1, Q7.3 (E), R37.1, R38.1, R47.1, U1.8 (V+), U2.8 (V+), U3.8 (V+), U4.11 (V+), U5.8 (V+), U6.8 (V+), U7.8 (V+), U8.3 (OUT)
-15V: C16.2, C17.2, C18.2, C19.2, C20.2, C21.2, C22.2, C23.2, D12.1 (K), J3.2, J4.2, J8.3, J9.3, R35.2, U1.4 (V-), U2.4 (V-), U3.4 (V-), U4.6 (V-), U5.4 (V-), U6.4 (V-), U7.4 (V-), U9.3 (VO); also elsewhere on the board
BIAS: R47.2, R48.1; also elsewhere on the board
CCS1: Q8.1 (C); also elsewhere on the board
CCS2: Q9.1 (C); also elsewhere on the board
GND: C13.2, C14.1, C15.2, C16.1, D13.2 (A), J2.3, J2.4, J3.3, J4.3, J7.1, J8.2, J9.2, R36.2, R48.2, U8.2 (GND), U9.1 (GND); also elsewhere on the board
INPUT: J3.4; also elsewhere on the board
LIM_CTRL: J3.5, J4.4; also elsewhere on the board
unnamed: C13.1, D7.1 (K), D8.1 (K), D11.1 (K), U8.1 (IN)
unnamed: C14.2, D9.2 (A), D10.2 (A), D12.2 (A), U9.2 (VI)
unnamed: D8.2 (A), D9.1 (K), J2.2
unnamed: D7.2 (A), D10.1 (K), J2.1
unnamed: D13.1 (K), R35.1
unnamed: Q7.1 (C), Q8.2 (B), Q9.2 (B), R36.1
unnamed: Q7.2 (B), Q8.3 (E), R37.2
unnamed: Q9.3 (E), R38.2
OUTPUT: J3.7; also elsewhere on the board
PRE_CTRL: J3.6, J4.5; also elsewhere on the board

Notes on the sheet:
Dual current source
Rectifier back-bias
POWER
36V AC CT 15VA

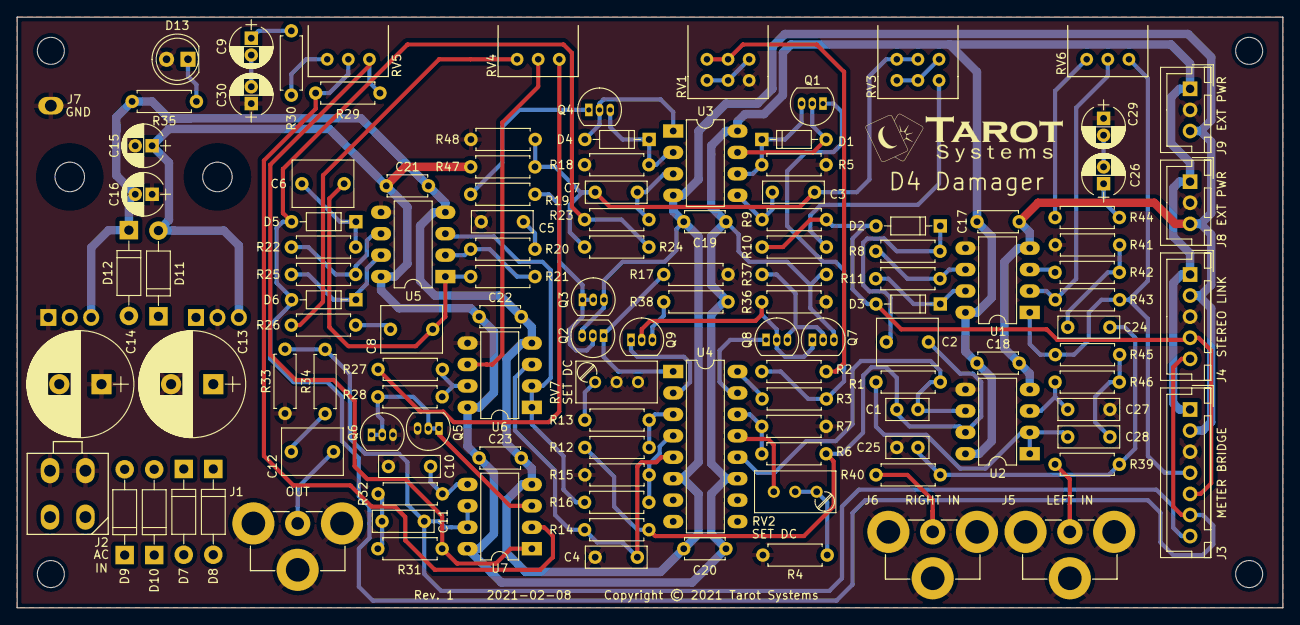
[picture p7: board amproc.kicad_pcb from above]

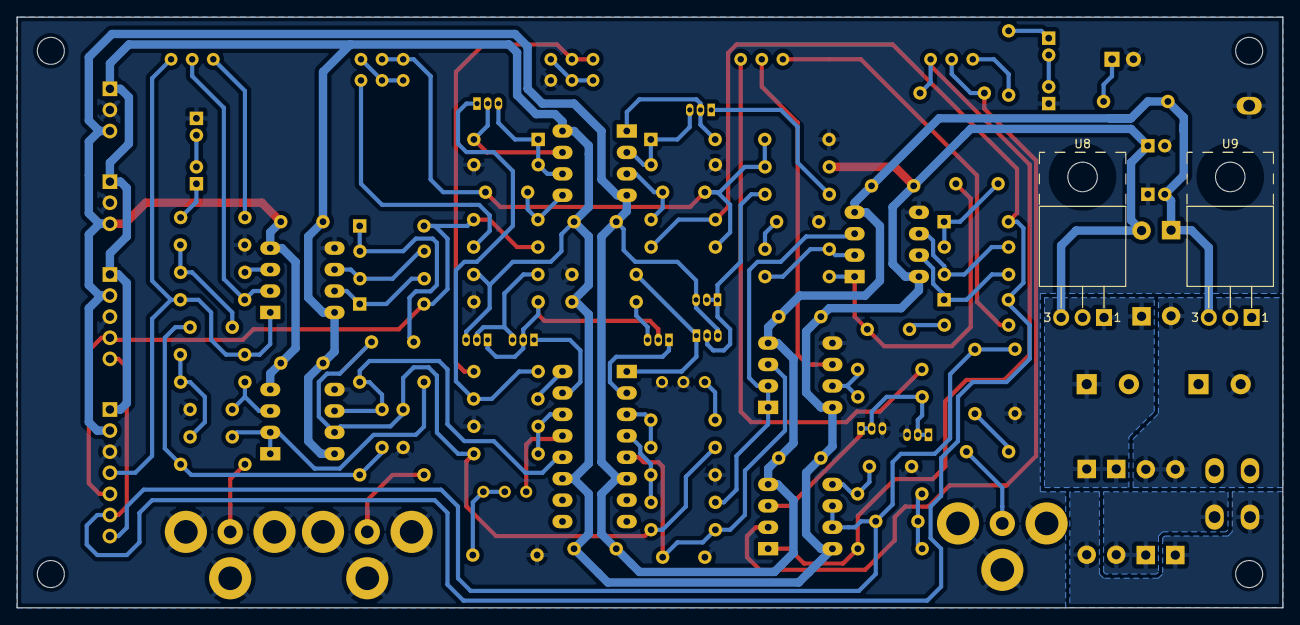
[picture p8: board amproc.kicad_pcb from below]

Board: 2 copper layers, 150.0 x 70.0 mm, 130 parts (2 on the bottom side), 79 nets.

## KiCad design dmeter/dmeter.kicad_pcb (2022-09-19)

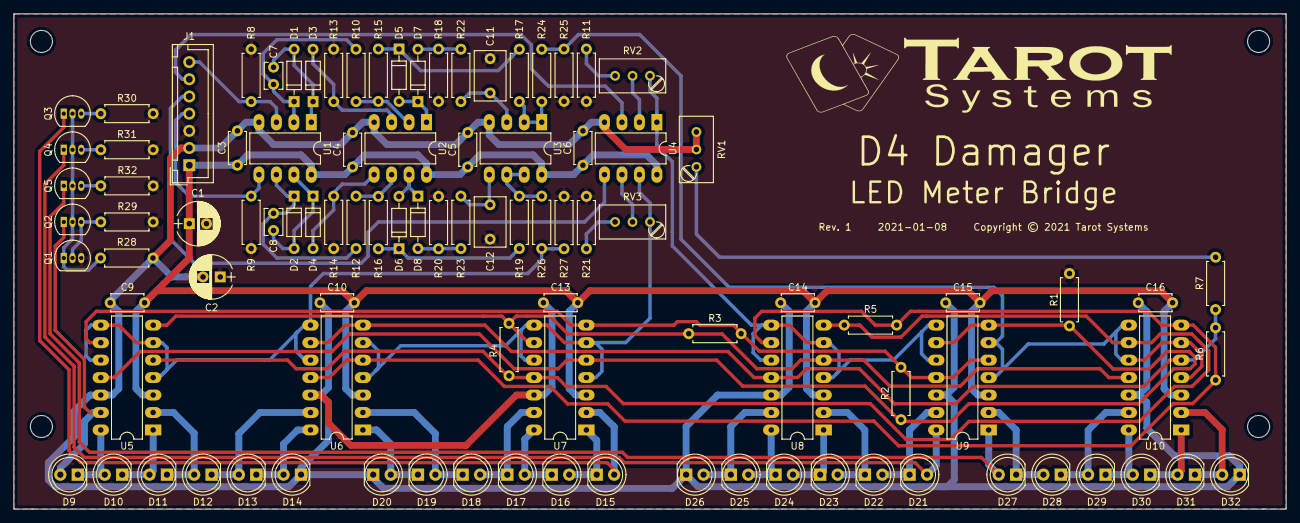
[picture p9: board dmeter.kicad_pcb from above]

Board: 2 copper layers, 185.0 x 72.0 mm, 104 parts (0 on the bottom side), 69 nets.

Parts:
C1, C2: 100u 25V; CP_Radial_D6.3mm_P2.50mm
C3, C4, C5, C6, C9, C10, C13, C14, C15, C16: 100n; C_Disc_D4.7mm_W2.5mm_P5.00mm
C7, C8: 33p; C_Disc_D3.8mm_W2.6mm_P2.50mm
C11, C12: 560n; C_Rect_L7.2mm_W4.5mm_P5.00mm_FKS2_FKP2_MKS2_MKP2
D1, D2, D3, D4, D5, D6, D7, D8: 1N4148; D_DO-35_SOD27_P7.62mm_Horizontal
D9, D10, D11, D12, D15, D16, D17, D18, D19, D20, D21, D22, D23, D24, D25, D26, D27, D28, D29, D30: GREEN; LED_D5.0mm
D13, D31: YELLOW; LED_D5.0mm
D14, D32: RED; LED_D5.0mm
G1: LOGO; tarot_logo_fsilk_60mm
H1, H2, H3, H4: M3; MountingHole_3.2mm_M3
J1: INPUT; JST_XH_B07B-XH-A_07x2.50mm_Straight
Q1, Q2, Q3, Q4, Q5: BC556; TO-92_Inline_Narrow_Oval
R1, R2: 1k; R_Axial_DIN0207_L6.3mm_D2.5mm_P7.62mm_Horizontal_FabText
R3: 2k; R_Axial_DIN0207_L6.3mm_D2.5mm_P7.62mm_Horizontal_FabText
R4: 3k9; R_Axial_DIN0207_L6.3mm_D2.5mm_P7.62mm_Horizontal_FabText
R5: 8k2; R_Axial_DIN0207_L6.3mm_D2.5mm_P7.62mm_Horizontal_FabText
R6: 16k; R_Axial_DIN0207_L6.3mm_D2.5mm_P7.62mm_Horizontal_FabText
R7: 240k; R_Axial_DIN0207_L6.3mm_D2.5mm_P7.62mm_Horizontal_FabText
R8, R9, R10, R12, R13, R14, R15, R16, R17, R19, R24, R25, R27: 10k; R_Axial_DIN0207_L6.3mm_D2.5mm_P7.62mm_Horizontal_FabText
R11, R21: 390; R_Axial_DIN0207_L6.3mm_D2.5mm_P7.62mm_Horizontal_FabText
R18, R20: 1M; R_Axial_DIN0207_L6.3mm_D2.5mm_P7.62mm_Horizontal_FabText
R22, R23, R28: 5k6; R_Axial_DIN0207_L6.3mm_D2.5mm_P7.62mm_Horizontal_FabText
R26: 30k; R_Axial_DIN0207_L6.3mm_D2.5mm_P7.62mm_Horizontal_FabText
R29, R30, R31, R32: 100; R_Axial_DIN0207_L6.3mm_D2.5mm_P7.62mm_Horizontal_FabText
RV1, RV2, RV3: 10k; Potentiometer_Trimmer_Bourns_3296W_FabText
U1, U2, U3, U4: TL072; DIP-8_W7.62mm_LongPads
U5, U6, U7, U8, U9, U10: LM339; DIP-14_W7.62mm_LongPads

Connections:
+15V: C1.1, C3.1, C4.1, C5.1, C6.1, C9.1, C10.1, C13.1, C14.1, C15.1, C16.1, J1.1, U1.8 (V+), U2.8 (V+), U3.8 (V+), U4.8 (V+), U5.3 (V+), U6.3 (V+), U7.3 (V+), U8.3 (V+), U9.3 (V+), U10.3 (V+)
-15V: C2.2, C3.2, C4.2, C5.2, C6.2, C9.2, C10.2, C13.2, C14.2, C15.2, C16.2, D14.1 (K), D20.1 (K), D26.1 (K), D32.1 (K), J1.2, R28.2, RV1.2, RV1.3, U1.4 (V-), U2.4 (V-), U3.4 (V-), U4.4 (V-), U5.12 (V-), U6.12 (V-), U7.12 (V-), U8.12 (V-), U9.12 (V-), U10.12 (V-)
/VU0: R6.2, R7.1, U6.7 (+), U6.9 (+), U8.11 (+), U10.5 (+)
/VU6: R5.2, R6.1, U6.5 (+), U6.11 (+), U8.9 (+), U10.7 (+)
/VU12: R4.2, R5.1, U5.5 (+), U7.11 (+), U8.7 (+), U10.9 (+)
/VU18: R3.2, R4.1, U5.7 (+), U7.9 (+), U8.5 (+), U10.11 (+)
/VU24: R2.2, R3.1, U5.9 (+), U7.7 (+), U9.5 (+), U9.11 (+)
/VU30: R1.2, R2.1, U5.11 (+), U7.5 (+), U9.7 (+), U9.9 (+)
GND: C1.2, C2.1, C11.2, C12.2, J1.3, Q1.3 (E), R1.1, R8.2, R9.2, R11.2, R13.2, R14.2, R18.2, R20.2, R21.2, R25.2, R27.2, R29.1, R30.1, R31.1, R32.1
unnamed: C7.1, D1.1 (K), R10.2, U1.2 (-)
unnamed: C7.2, D1.2 (A), D3.1 (K), U1.1
unnamed: C8.1, D2.1 (K), R12.2, U1.6 (-)
unnamed: C8.2, D2.2 (A), D4.1 (K), U1.7
unnamed: C11.1, R22.1, U3.3 (+)
unnamed: C12.1, R23.1, U3.5 (+)
unnamed: D3.2 (A), R13.1, U2.3 (+)
unnamed: D4.2 (A), R14.1, U2.5 (+)
unnamed: D5.1 (K), R15.1, R17.2
unnamed: D5.2 (A), D7.1 (K), U2.1
unnamed: D6.1 (K), R16.1, R19.2
unnamed: D6.2 (A), D8.1 (K), U2.7
unnamed: D7.2 (A), R18.1, R22.2
unnamed: D8.2 (A), R20.1, R23.2
unnamed: D9.2 (A), Q2.1 (C), U5.13
unnamed: D10.1 (K), D11.2 (A), U5.1
unnamed: D9.1 (K), D10.2 (A), U5.14
unnamed: D11.1 (K), D12.2 (A), U5.2
unnamed: D12.1 (K), D13.2 (A), U6.13
unnamed: D13.1 (K), D14.2 (A), U6.14
unnamed: D15.1 (K), D16.2 (A), U7.1
unnamed: D15.2 (A), Q3.1 (C), U7.2
unnamed: D16.1 (K), D17.2 (A), U7.14
unnamed: D17.1 (K), D18.2 (A), U7.13
unnamed: D18.1 (K), D19.2 (A), U6.2
unnamed: D19.1 (K), D20.2 (A), U6.1
unnamed: D21.1 (K), D22.2 (A), U9.13
unnamed: D21.2 (A), Q4.1 (C), U9.14
unnamed: D22.1 (K), D23.2 (A), U8.2
unnamed: D23.1 (K), D24.2 (A), U8.1
unnamed: D24.1 (K), D25.2 (A), U8.14
unnamed: D25.1 (K), D26.2 (A), U8.13
unnamed: D27.1 (K), D28.2 (A), U9.2
unnamed: D27.2 (A), Q5.1 (C), U9.1
unnamed: D28.1 (K), D29.2 (A), U10.13
unnamed: D29.1 (K), D30.2 (A), U10.14
unnamed: D30.1 (K), D31.2 (A), U10.1
unnamed: D31.1 (K), D32.2 (A), U10.2
unnamed: J1.4, R9.1, U1.5 (+)
unnamed: J1.5, U4.5 (+)
unnamed: J1.6, U4.3 (+)
unnamed: J1.7, R8.1, U1.3 (+)
unnamed: Q1.1 (C), Q2.2 (B), Q3.2 (B), Q4.2 (B), Q5.2 (B), R28.1
unnamed: Q1.2 (B), Q2.3 (E), R29.2
unnamed: Q3.3 (E), R30.2
unnamed: Q4.3 (E), R31.2
unnamed: Q5.3 (E), R32.2
unnamed: R7.2, RV1.1
unnamed: R10.1, R15.2, U2.2 (-)
unnamed: R11.1, RV2.3
unnamed: R12.1, R16.2, U2.6 (-)
unnamed: R17.1, R24.1, U3.1, U3.2 (-)
unnamed: R19.1, R26.1, U3.6 (-), U3.7
unnamed: R21.1, RV3.3
unnamed: R24.2, R25.1, U9.4 (-), U9.6 (-), U10.4 (-), U10.6 (-), U10.8 (-), U10.10 (-)
unnamed: R26.2, R27.1, U5.4 (-), U5.6 (-), U5.8 (-), U5.10 (-), U6.8 (-), U6.10 (-)
unnamed: RV2.1, U4.1, U8.4 (-), U8.6 (-), U8.8 (-), U8.10 (-), U9.8 (-), U9.10 (-)
unnamed: RV2.2, U4.2 (-)
unnamed: RV3.1, U4.7, U6.4 (-), U6.6 (-), U7.4 (-), U7.6 (-), U7.8 (-), U7.10 (-)
unnamed: RV3.2, U4.6 (-)

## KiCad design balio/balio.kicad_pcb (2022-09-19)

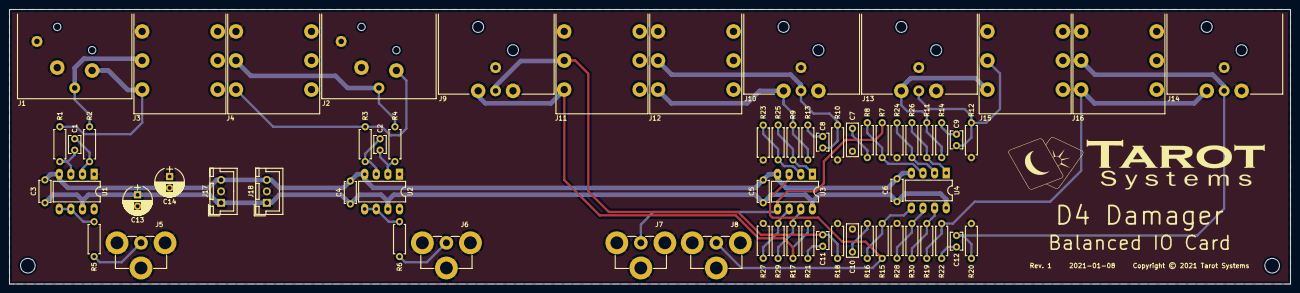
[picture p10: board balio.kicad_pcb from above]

Board: 2 copper layers, 280.0 x 60.0 mm, 69 parts (0 on the bottom side), 41 nets.

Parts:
C1, C2, C8, C9, C11, C12: 560p; C_Disc_D3.8mm_W2.6mm_P2.50mm
C3, C4, C5, C6: 100n; C_Disc_D4.7mm_W2.5mm_P5.00mm
C7, C10: *; C_Rect_L7.2mm_W2.5mm_P5.00mm_FKS2_FKP2_MKS2_MKP2
C13, C14: 100u 25V; CP_Radial_D6.3mm_P2.50mm
G1: LOGO; tarot_logo_fsilk_60mm
H1, H2: M3; MountingHole_3.2mm_M3
J1: IN1; NC3FAAH2
J2: IN2; NC3FAAH2
J3: IN1; CL12345
J4: IN2; CL12345
J5: OUT1; NYS354
J6: OUT2; NYS354
J7: IN3; NYS354
J8: IN4; NYS354
J9: OUT3; NC3MAAH
J10: OUT4; NC3MAAH
J11: OUT3; CL12345
J12: OUT4; CL12345
J13: MON3; NC3MAAH
J14: MON4; NC3MAAH
J15: MON3; CL12345
J16: MON4; CL12345
J17, J18: POWER; JST_XH_B03B-XH-A_03x2.50mm_Straight
R1, R2, R3, R4, R23, R24, R25, R26, R27, R28, R29, R30: 2k2; R_Axial_DIN0207_L6.3mm_D2.5mm_P7.62mm_Horizontal_FabText
R5, R6, R9, R10, R11, R12, R13, R14, R17, R18, R19, R20, R21, R22: 220; R_Axial_DIN0207_L6.3mm_D2.5mm_P7.62mm_Horizontal_FabText
R7, R8, R15, R16: *; R_Axial_DIN0207_L6.3mm_D2.5mm_P7.62mm_Horizontal_FabText
U1, U2: INA134; DIP-8_W7.62mm_LongPads
U3, U4: TL072; DIP-8_W7.62mm_LongPads

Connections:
+15V: C3.2, C4.2, C5.1, C6.1, C13.1, J17.1, J18.1, U1.7 (VDD), U2.7 (VDD), U3.8 (V+), U4.8 (V+)
-15V: C3.1, C4.1, C5.2, C6.2, C14.2, J17.3, J18.3, U1.4 (VSS), U2.4 (VSS), U3.4 (V-), U4.4 (V-)
GND: C7.2, C10.2, C13.2, C14.1, J1.1, J1.G, J2.1, J2.G, J3.S, J4.S, J5.2 (Ext), J6.2 (Ext), J7.2 (Ext), J8.2 (Ext), J9.1, J9.G, J10.1, J10.G, J11.S, J12.S, J13.1, J13.G, J14.1, J14.G, J15.S, J16.S, J17.2, J18.2, R10.2, R12.2, R18.2, R20.2, R23.1, R24.1, R27.1, R28.1, U1.1 (REF), U2.1 (REF)
unnamed: C1.1, R2.1, U1.2 (IN-)
unnamed: C1.2, R1.1, U1.3 (IN+)
unnamed: C2.1, R4.1, U2.2 (IN-)
unnamed: C2.2, R3.1, U2.3 (IN+)
unnamed: C7.1, R8.2
unnamed: C8.1, R13.1
unnamed: C8.2, J10.3, J12.R, R10.1
unnamed: C9.1, R14.1
unnamed: C9.2, J13.3, J15.R, R12.1
unnamed: C10.1, R16.2
unnamed: C11.1, R21.1
unnamed: C11.2, J9.3, J11.R, R18.1
unnamed: C12.1, R22.1
unnamed: C12.2, J14.3, J16.R, R20.1
unnamed: J1.2, J3.T, R1.2
unnamed: J1.3, J3.R, R2.2
unnamed: J2.2, J4.T, R3.2
unnamed: J2.3, J4.R, R4.2
unnamed: J5.1 (In), R5.1
unnamed: J6.1 (In), R6.1
unnamed: J7.1 (In), R7.1, U3.5 (+)
unnamed: J8.1 (In), R15.1, U3.3 (+)
unnamed: J10.2, J12.T, R9.1, R13.2
unnamed: J9.2, J11.T, R17.1, R21.2
unnamed: J13.2, J15.T, R11.1, R14.2
unnamed: J14.2, J16.T, R19.1, R22.2
unnamed: R5.2, U1.5 (SENSE), U1.6 (OUT)
unnamed: R6.2, U2.5 (SENSE), U2.6 (OUT)
unnamed: R7.2, R8.1, U4.3 (+)
unnamed: R9.2, R25.1, U3.1
unnamed: R11.2, R26.1, U4.1
unnamed: R15.2, R16.1, U4.5 (+)
unnamed: R17.2, R29.1, U3.7
unnamed: R19.2, R30.1, U4.7
unnamed: R23.2, R25.2, U3.2 (-)
unnamed: R24.2, R26.2, U4.2 (-)
unnamed: R27.2, R29.2, U3.6 (-)
unnamed: R28.2, R30.2, U4.6 (-)

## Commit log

2021-07-12 First rev PCBs
    [BoM am na.xlsx, BoM am row.xlsx, BoM core.xlsx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]
2021-07-12 Change C25 to 100pF to reduce high frequency attenuation
    [BoM am na.xlsx, BoM am row.xlsx, BoM core.xlsx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]
2021-07-12 Change R24 to 10k, R26 to 30k to correct input/output meter reference levels
    [BoM.xlsx, dmeter.sch]
2021-07-14 Changed LPF, pre-emphasis component values in AM (NA and RoW) variants to correct bandwidth
    [BoM am na.xlsx, BoM am row.xlsx, InputStage.sch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]
2021-07-14 Changed Balanced IO card de-emphasis circuit in AM RoW variant to match pre-emphasis changes in previous commit
    [BoM am row.xlsx, balio.sch]
2021-07-14 Fixed some BoM formatting issues
    [BoM fm row.xlsx, BoM.xlsx]
2021-07-17 Fixed molex connector pin diameter
    [amproc.kicad_pcb]
2021-07-17 Optimise pre-emphasis network values
    [BoM fm na.xlsx, BoM fm row.xlsx, Preemphasis.sch]
2022-09-19 Upgrade amproc to Kicad 6
    [InputStage.kicad_sch, InputStage.sch, Limiter.kicad_sch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]
2022-09-19 Upgrade balio to Kicad 6
    [balio.kicad_pcb, balio.kicad_sch, balio.sch]
2022-09-19 Upgrade dmeter to Kicad 6
    [dmeter.kicad_pcb, dmeter.kicad_sch, dmeter.sch]
2022-09-19 Fix U8, U9 pinouts
    [InputStage.kicad_sch, Limiter.kicad_sch, OutputStage.kicad_sch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]
2022-09-19 Change R10 to 430k to increase minimum release time
    [BoM am na.xlsx, BoM am row.xlsx, BoM core.xlsx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]

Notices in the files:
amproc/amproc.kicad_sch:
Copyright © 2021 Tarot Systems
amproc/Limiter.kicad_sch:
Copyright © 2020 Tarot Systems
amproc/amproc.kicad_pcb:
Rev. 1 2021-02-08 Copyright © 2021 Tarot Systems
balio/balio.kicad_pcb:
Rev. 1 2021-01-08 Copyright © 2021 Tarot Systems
